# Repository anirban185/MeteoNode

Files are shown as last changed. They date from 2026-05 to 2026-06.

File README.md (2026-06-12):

# MeteoNode
 
MeteoNode is a small solar-powered ESP32 weather node. The idea is to pull regional forecast data from Open-Meteo and adjust it using pressure, humidity, and temperature trends measured locally by the node itself. Instead of sending data somewhere else to process, the ESP32 handles everything on-device using a lightweight Bayesian-style system.

# Why
 
Regional forecasts are accurate at scale but they update slowly. Local pressure drops and humidity spikes can show incoming weather changes earlier than a regional model would catch. I wanted to see if those local trends could make a forecast feel more responsive at a specific location on a small standalone device.
 
Something like:
 
```
Open-Meteo rain chance: 40%
Pressure dropping fast
Humidity rising
 
=> local adjusted: 65%
```
 
It's not meant to replace anything. More of an experiment.

# How I built it
 
Most of the early time went into research and parts selection, not actual building.
 
My original sensor choice was the BME280 because it handles temperature, humidity, and pressure in one chip. While reading through datasheets and long-term testing threads I found that combined environmental sensors can slightly skew their own readings because of internal heat generation. So I split it into a BMP280 for pressure and an HTU21D for temperature and humidity. Separating them also made physical placement easier since they no longer needed to sit right next to each other.
 
The power system took the longest.
 
I initially looked at the TP4056 for charging but solar panels don't output stable voltage, they fluctuate constantly depending on sunlight and load. The TP4056 needs a stable input to work properly. I switched to the TP5000 because its buck converter handles variable input between 4.5V and 9V without needing anything extra to stabilize it.
 
For the battery I moved away from standard 18650 Li-ion. The node is meant to sit outside unattended in direct sun, and Li-ion can go into thermal runaway at high temperatures. LiFePO4 needs over 270°C to reach thermal runaway and doesn't sustain a fire even if it does ignite, so it was the obvious choice. I went with a Huaxing 32700 6000mAh solar grade cell.
 
Powering the ESP32 directly from the LiFePO4 cell also came with a problem I found during research. During WiFi transmission the ESP32 pulls sudden high current spikes that can drop the supply voltage and cause brownouts and random reboots, especially with solar-grade cells or long wiring. To fix that I added a 1000uF electrolytic capacitor for the transient demand and a 100nF ceramic for high-frequency RF decoupling.
 
The soft-latch circuit was probably the most interesting part. The node runs on a deep sleep cycle normally, but I also wanted a way for it to fully disconnect itself if the battery stays critically low for too long, to avoid deep discharge damage. The circuit uses an FDN304P P-channel MOSFET as the main switch and a 2N7000 N-channel to control it. The ESP32 holds the latch on after waking. If battery voltage drops below the cutoff the firmware pulls the latch low, the MOSFET opens, and power is cut completely. Manual restart needed after that.
 
One more thing the direct battery connection created was an ADC reference problem. Since the ESP32 runs off the cell directly there is no stable 3.3V reference, so the ADC reading drifts with battery voltage. The firmware handles this by reading the ESP32's internal 1.1V bandgap reference each wake cycle and using it to calculate the actual VREF before reading the battery.

# Enclosure
 
I wanted the enclosure done properly, not just a box you shove everything into.
 
The first decision was keeping the battery separate from the main electronics. The battery generates heat when charging, and heat near the sensors would throw off the readings, so the battery got its own compartment. I modeled it around the actual cell dimensions (32.2 x 70.5mm), added two side holes for the wires to pass through (a center hole would've conflicted with the pole clamp), and added tabs on both the box and lid for M3 bolts. There are grooves on the mating faces for O-rings to seal it.
 
The main electronics box went through a couple of iterations. I first made a single box, then split the interior into two sections: a sealed ESP32/power side and a vented sensor side. I live in a part of Assam where humidity sits between 80 and 90 percent most of the year and hits 100 during monsoon. The ESP side is fully sealed with an O-ring groove on the lid. The sensor side has ventilation holes so the HTU21D is actually reading ambient air, not trapped air. I added rails inside both sides to mount the sensors and perfboard without floating them around loose.
 
For mounting I took inspiration from motor shaft couplers. I made a pipe-shaped clamp that slides over the main pole with set screws, and bolted the electronics box to that. The whole thing sits on a 2-meter pole with a rectangular channel running through it for the battery wires.
 
Since I couldn't find the O-rings I needed, I ended up making gaskets instead and finished the assembly.
 
CAD files are in `Hardware/Cad files/` as STEP files. There's a full assembly plus individual parts: battery box, main electronics box, pole mount bracket, and pole.

OnShape Link: https://cad.onshape.com/documents/560823f845b4e1dbdcd98f5f/w/6feb564b6c844b09aff696f7/e/17a8fd3166888350d1755295

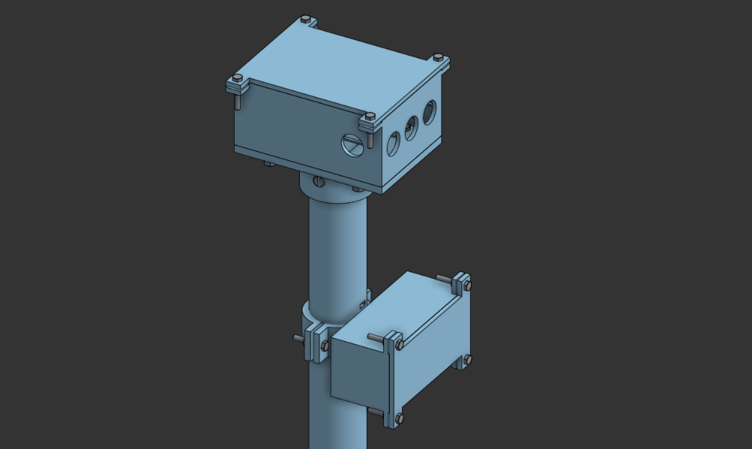
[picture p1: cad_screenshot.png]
cad Screenshot

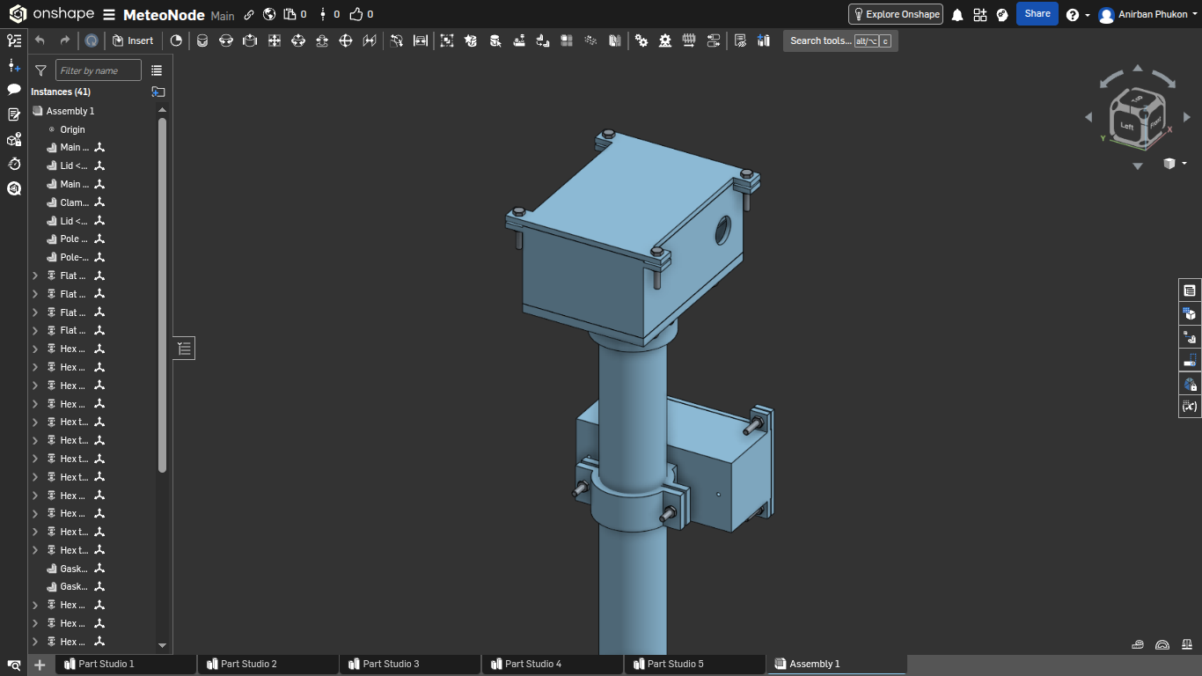
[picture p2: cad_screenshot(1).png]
cad_screenshot(1)

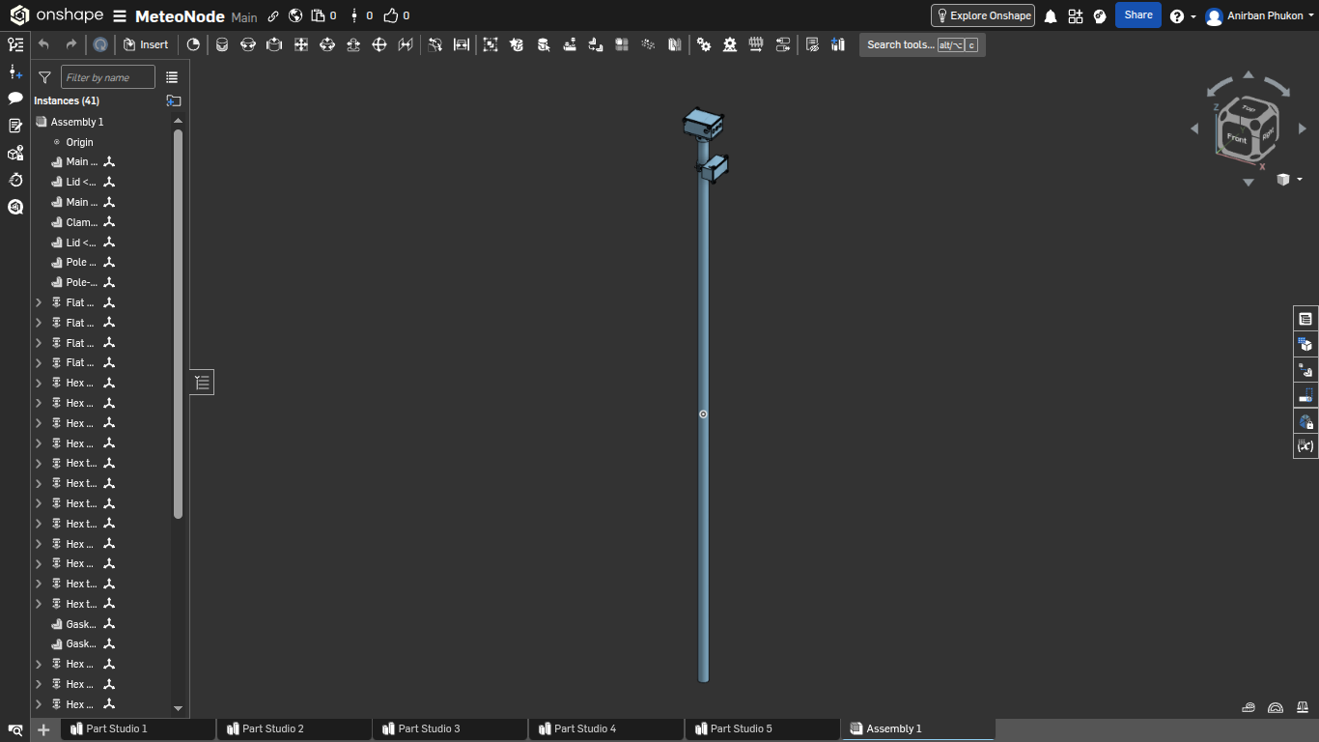
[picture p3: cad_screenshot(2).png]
cad screenshot(2)


# Hardware
 
| Component | Purpose |
|---|---|
| ESP32-WROOM-32UE Dev Board | Main controller |
| BMP280 | Pressure sensor |
| HTU21D | Temperature and humidity sensor |
| TP5000 Charge Module | LiFePO4 solar charging |
| Huaxing 32700 6000mAh LiFePO4 | Power storage |
| 2W 5V Solar Panel ×2 | Solar input |
| FDN304P P-Channel MOSFET | High-side power switch |
| 2N7000 N-Channel MOSFET | Soft-latch control |
| 1000uF Electrolytic Capacitor | WiFi current spike stabilization |
| 100nF Ceramic Capacitor | RF decoupling |
| 1N5819 Schottky Diode | Reverse current protection |
| 3A Glass Fuse + Holder | Overcurrent protection |
| MT76813DBI WiFi Antenna | External antenna |
| 100K Resistor | Voltage divider + PMOS gate pull-up |
| 10K Resistor | NMOS gate pull-down |
| 1K Resistor | ESP32 overcurrent protection |
 
Everything is from ElectronicsComp.

# Block diagram
 
block diagram

# Wiring diagram

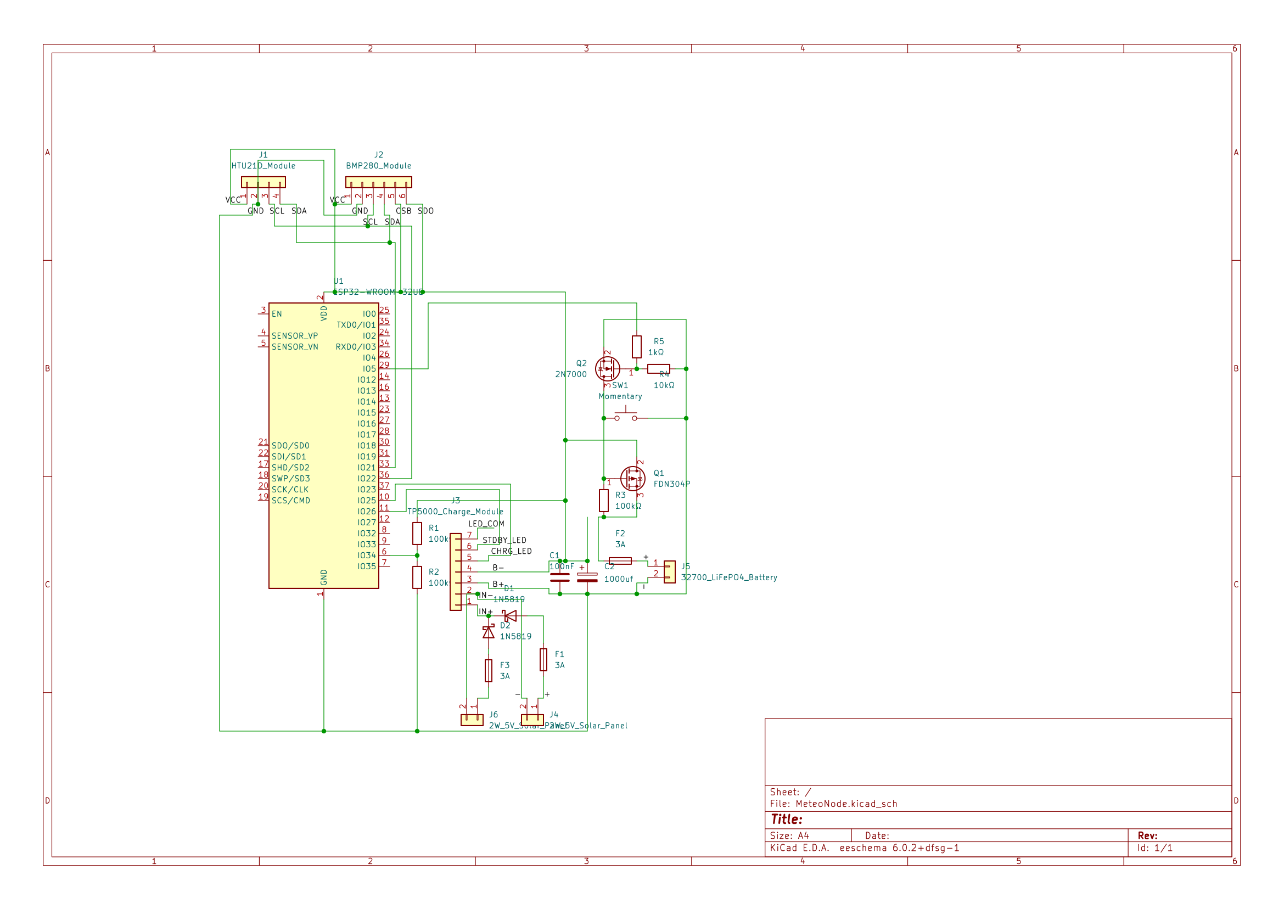
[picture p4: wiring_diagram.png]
block diagram


Open the image in a new tab and zoom to view it in full resolution.

# Firmware
 
Each wake cycle the ESP32 reads the sensors, fetches a forecast from Open-Meteo, adjusts the rain probability using local trends from RTC memory, and goes back to sleep. RTC memory keeps the last 4 readings alive across deep sleep so the trend analysis always has something to work with.
 
Full setup and wiring details are in `Firmware/README.md`.

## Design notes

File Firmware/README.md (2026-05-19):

## MeteoNode Firmware
 
This is the firmware for the MeteoNode. The core idea is to wake up, read the sensors, pull a regional forecast from Open-Meteo, adjust the rain probability using local pressure and humidity trends, and go back to sleep. Everything runs on the ESP32 locally, no external processing.

## Libraries
 
Install these through PlatformIO or the Arduino Library Manager. If you're using the platformio.ini it will handle this automatically.
 
- Adafruit BMP280
- Adafruit Unified Sensor
- HTU21D (enjoyneering's version)
- ArduinoJson v7
 
## Setup
 
At the top of `Firmware.ino` there are defines for WiFi credentials and the node's coordinates. These need to be set before flashing.
 
```cpp
#define WIFI_SSID        "YOUR_SSID"
#define WIFI_PASSWORD    "YOUR_PASSWORD"
 
#define LATITUDE         "Node's Latitude"
#define LONGITUDE        "Node's Longitude"
```
 
The coordinates are passed directly to the Open-Meteo API, so they should be as accurate as possible for the forecast to be useful. `SLEEP_SECONDS` is 15 minutes by default. `LATCH_HOLD_PIN` is GPIO5, change it if the 2N7000 gate is wired differently.

## Wiring
 
**I2C**  Both sensors share the same bus.
- SDA  GPIO 21
- SCL  GPIO 22
- BMP280 default address is 0x76, code tries 0x77 as a fallback
- HTU21D is always 0x40
**Battery ADC**  100K-100K voltage divider into GPIO34.
```
BAT+  100K  GPIO34  100K  GND
```
 
**Soft latch**  GPIO5 held HIGH keeps the system on. When battery voltage drops below the critical threshold the firmware pulls it LOW, the MOSFET latch opens, and power is cut completely. After that it requires a manual restart.

## Battery Voltage and the ADC Problem
 
Since the ESP32 is powered directly from the LiFePO4 cell there is no stable 3.3V reference for the ADC. The supply voltage shifts between roughly 3.0V and 3.6V depending on charge state, which would make a fixed-reference ADC reading meaningless.
 
To fix this the firmware reads the ESP32's internal 1.1V bandgap reference on every wake cycle and uses that to figure out what VREF actually is at that moment. The battery voltage is then calculated using the calibrated VREF rather than assuming a fixed value. It's not laboratory accurate but it's consistent and close enough to catch low voltage events reliably.
 
Thresholds:
- Below 2.90V  cuts power via latch
- Below 3.00V  skips WiFi, reads sensors and sleeps
- Normal otherwise
 
## Wake Cycle
 
Every time the ESP32 wakes from deep sleep it runs through this sequence:
 
1. Hold latch pin HIGH immediately so the system stays on
2. Read battery voltage, cut power or skip WiFi if needed
3. Read BMP280 and HTU21D over I2C
4. Push readings into the RTC ring buffer
5. Connect to WiFi and fetch Open-Meteo forecast if battery allows
6. Calculate adjusted local rain probability
7. Print report to serial
8. Sleep for `SLEEP_SECONDS`
The RTC ring buffer stores the last 4 pressure, humidity, and temperature readings across sleep cycles. It needs at least 2 samples before trend analysis activates. At 15 minute intervals that means one hour of history to work with.

## Forecast Adjustment
 
Open-Meteo provides a regional rain probability. The local sensors can sometimes pick up changes faster, pressure drops in particular tend to precede incoming weather before the regional model updates. The firmware calculates a slope across the RTC history for pressure, humidity, and temperature and uses that to shift the Open-Meteo probability up or down.
 
The adjustment runs in logit space rather than raw percentage so the result stays naturally bounded between 0 and 100 without any clamping.
 
The next 3 hourly values from Open-Meteo are averaged to smooth out short-term noise before the adjustment is applied.

## Serial Output
 
Baud rate is 115200. A typical cycle looks like this:
 
```
boot 4
bat: 3.31V
P=1008.42 hPa T=27.3 C H=81.2% Bat=3.31V
wifi connecting.... ok
forecast: rain=42.0% temp=28.1C hum=79.0%
--- meteonode ---
boot #4
battery: 3.31V
pressure: 1008.42 hPa
temp: 27.3C
humidity: 81.2%
open-meteo rain: 42.0%
local adjusted: 61.3%
condition: Likely Rain
----------------
sleeping 900s
```
 
Disconnect serial before deploying outside. Keeping UART active draws extra current through the whole sleep cycle.

## Security Note
 
The firmware uses `client.setInsecure()` to connect to Open-Meteo over HTTPS. The connection is encrypted but the server identity is not verified because pinning a certificate on an ESP32 is more complexity than this project needs. Fine for a local weather node on a home network, but worth knowing if you're deploying it somewhere else.

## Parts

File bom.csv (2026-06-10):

Name | Purpose | Quantity | Total Cost (USD) | Link | Distributor
10K ohm Resistor | Gate pull-down resistor for the NMOS | 5 | 0.03 | https://www.electronicscomp.com/10k-ohm-resistance?search=10k%20Ohm%20resistor | ElectronicsComp
100K ohm Resistor | Battery monitor and PMOS gate pull-up resistor. | 5 | 0.03 | https://www.electronicscomp.com/100k-ohm-resistance?search=100k%20Ohm%20resistor | ElectronicsComp
1K ohm Resistor | Protection for the ESP32 from Overcurrent | 5 | 0.03 | https://www.electronicscomp.com/1k-ohm-resistance?search=1k%20Ohm%20resistor | ElectronicsComp
2N7000 N-Channel MOSFET | Electronic lock for the Soft-Latch | 2 | 0.20 | https://www.electronicscomp.com/2n7000-n-channel-enhancement-mode-fet-to-92-package?search=2N7000 | ElectronicsComp
FDN304P P-Channel MOSFET | Main power switch for soft-latch | 2 | 0.30 | https://www.electronicscomp.com/fdn304p-mosfet-smd-sot-23-package-20v-2.4a-p-channel-mosfet?search=FDN304P | ElectronicsComp
Fuse Holder | Housing for the glass fuse | 1 | 0.10 | https://www.electronicscomp.com/fuse-holder-pcb-mount-20mm?search=fuse%20holder | ElectronicsComp
3 Amp 250V Glass Fuse | Short-circuit protection | 6 | 0.25 | https://www.electronicscomp.com/3-amp-250v-glass-fuse-20mm?search=fuse&sort=p.price&order=ASC | ElectronicsComp
Prototyping Board | mounting and routing platform for core electronics | 2 | 1.00 | https://www.electronicscomp.com/6x8-cm-double-sided-universal-pcb-india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 | ElectronicsComp
28AWG Silicone Wire 10 m (Blue) | Logic Routing (I2C for AHT20/BMP280, ADC telemetry) | 1 | 0.60 | https://www.electronicscomp.com/tools-connectors/wires-cables/silicone-wires/24-to-30-awg/high-quality-ultra-flexible-28awg-silicone-wire-10-m-blue | ElectronicsComp
20AWG Silicone Wire 1m (Black) + 1m (Red) | Power Distribution (Solar, TP5000, Battery, ESP32 VIN/GND) | 1 | 1.10 | https://www.electronicscomp.com/tools-connectors/wires-cables/silicone-wires/18-to-22-awg/high-quality-ultra-flexible-20awg-silicone-wire-1m-black-1m-red | ElectronicsComp
MT76813DBI WiFi Antenna | Antenna for the ESP | 1 | 0.60 | https://www.electronicscomp.com/mt76813dbi-esp8266-serial-wifi-wireless-gain-antenna?search=wifi%20antenna | ElectronicsComp
100nf(0.1uf) Ceramic Capacitor | To decouple High-frequency RF noise | 5 | 0.05 | https://www.electronicscomp.com/0.1uf-104-ceramic-capacitor?search=capacitor%200.1uf | ElectronicsComp
1000uF 10V Electrolytic Capacitor | To stabilize voltage in wifi current spike | 2 | 0.25 | https://www.electronicscomp.com/1000uf-10v-electrolytic-capacitor?search=capacitor%201000uf | ElectronicsComp
ESP32-DevKitC ESP32-WROOM-32UE Development board | The main MCU | 1 | 7.25 | https://www.amazon.in/ESP32-DevKitC-32UE-ESP32-Devkit-Board-4MB/dp/B0CKPPQYCB/ | Amazon.in
Huaxing 32700 6000mAh Solar Grade LiFePO4 Battery | High-capacity 3.2V power storage | 1 | 2.50 | https://www.electronicscomp.com/hx-ifr32700-32v-6000mah-1c-lifepo4-battery-solar-grade?search=LiFePO4&page=2 | ElectronicsComp
TP5000 Charge Module | LiFePO4 Buck Charger | 1 | 1.00 | https://www.electronicscomp.com/tp5000-3.6v-4.2v-1a-lithiumbattery-charger-module?search=TP5000%20 | ElectronicsComp
1N5819 Schottky Diode | Reverse-Current Protection | 5 | 0.30 | https://www.electronicscomp.com/1n5419-schottky-barrier-diode?search=1N5819 | ElectronicsComp
2W 5V Solar Panel | 5V Power Generation | 2 | 4.00 | https://www.electronicscomp.com/robotics-parts-accesories/solar-panel-cell/solar-panel-5v-2w | ElectronicsComp
BMP280 Module | I2C Barometric Pressure Sensor | 1 | 0.90 | https://www.electronicscomp.com/bmp280-barometric-pressure-altitude-sensor-module-india?search=BMP280 | ElectronicsComp
HTU21D Module | Temperature & Humidity Sensor | 1 | 1.60 | https://www.electronicscomp.com/htu21d-temperature-and-humidity-sensor-module?search=HTu21 | ElectronicsComp

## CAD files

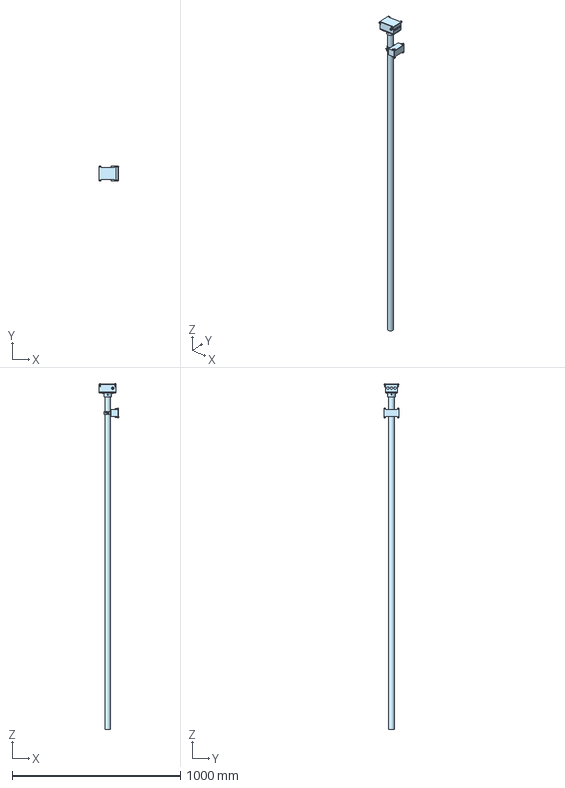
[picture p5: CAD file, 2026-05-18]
Hardware/Cad files/Assembly.step
116.0 x 90.0 x 2055.1 mm
Main battery compartment
Flat point slotted set screw M8x1.25 x 8 x 4
Lid x 2
Gasket x 2
Hex thin nut grade A & B M3 x 14
Hex head bolt grade B M3x0.50 x 20 x 10
Clamp
Pole
Pole-Mount Bracket
Main Box
Hex flange bolt small M5x0.80 x 10 x 4

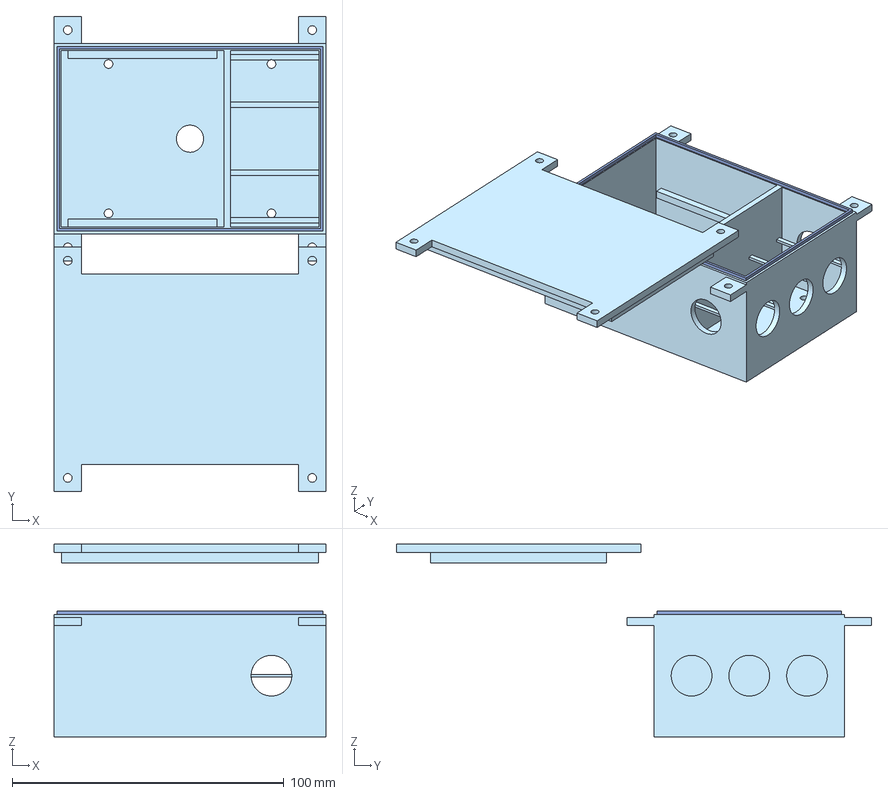
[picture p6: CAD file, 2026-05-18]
Hardware/Cad files/Main Electronics Box.step
100.0 x 174.9 x 70.9 mm

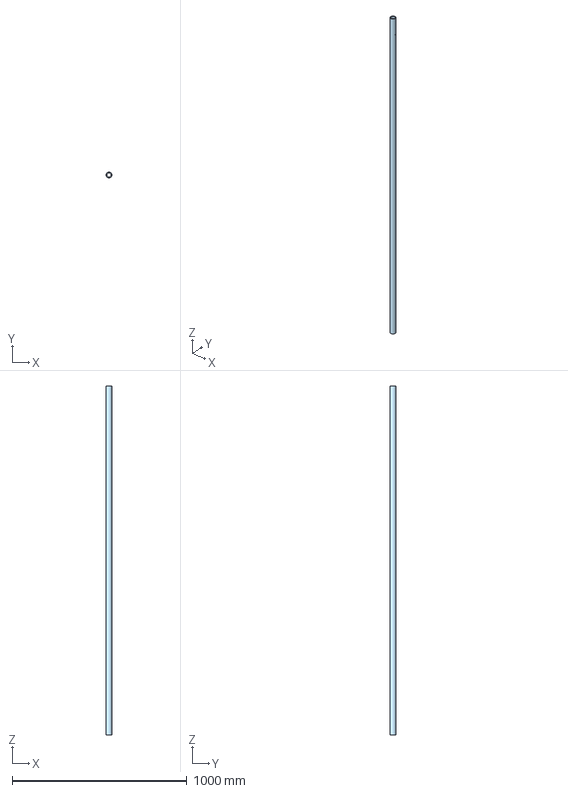
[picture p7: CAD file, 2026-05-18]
Hardware/Cad files/Pole.step
34.0 x 34.0 x 2000.0 mm

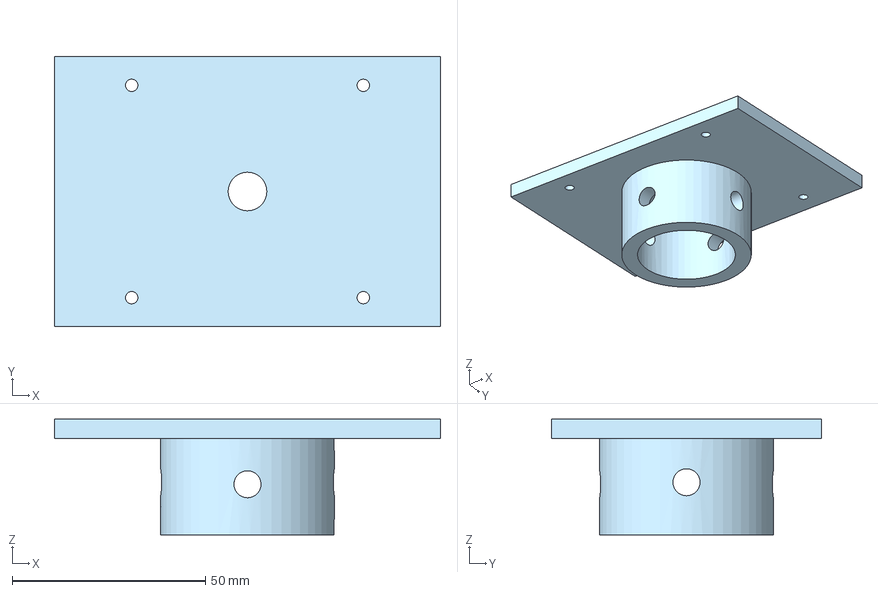
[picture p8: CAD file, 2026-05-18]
Hardware/Cad files/Pole-Mount Bracket.step
100.0 x 70.0 x 30.0 mm

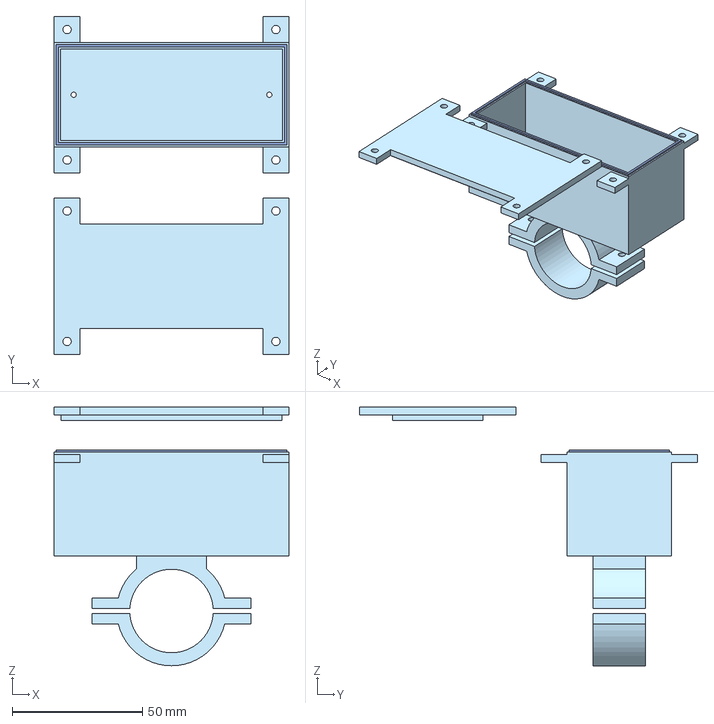
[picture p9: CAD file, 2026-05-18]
Hardware/Cad files/Battery Box.step
90.0 x 129.5 x 99.1 mm

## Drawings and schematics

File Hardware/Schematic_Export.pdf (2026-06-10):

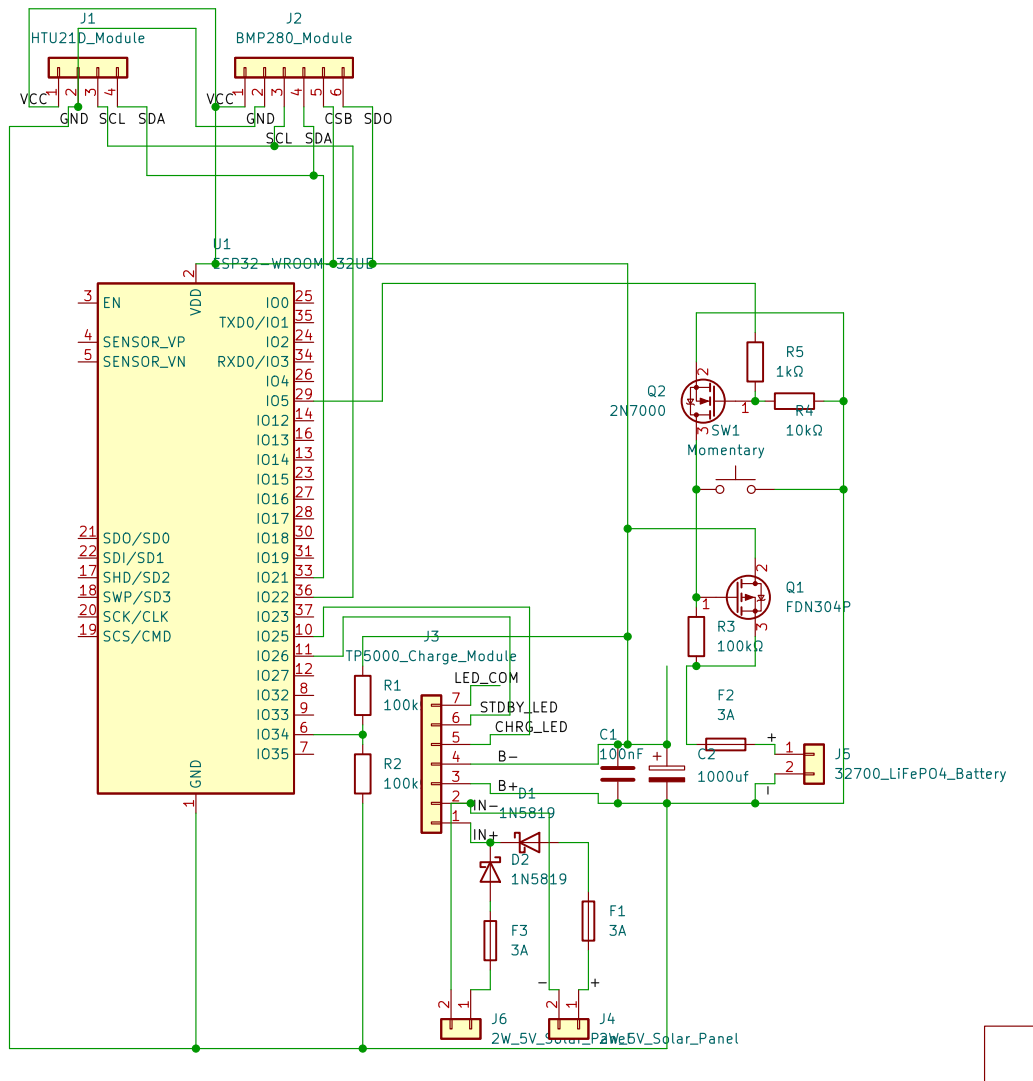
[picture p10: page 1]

2 SCK/CLK 20 SDO/SD0 21 SDI/SD1 22

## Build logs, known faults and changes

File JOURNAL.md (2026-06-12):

<!--
  This journal is auto generated by Stasis.
-->

# 6/12/2026 3 PM - Adjustments

_Time spent: 0.08333333333333333h_

According to the reviewer notes, my first and only task is adding CAD photos to the README, so I added some screenshots to the repo root and added them to the README.md. After this, I am gonna update the journal to include this entry on GitHub and resubmit.







# 6/10/2026 6 PM - Adjustments

_Time spent: 0.75h_

Based on the design feedback, my first task is renaming the BOM to bom.csv, which I did, but I didn’t have the energy to continue and went to bed without writing the journal. 

The next task is adding a diagram image to the read me, which was easy enough because my schematic was built to be a wiring diagram too, so I plotted it into a PDF, converted it into PNG and added it to the readme. While doing that,

 I had 2 resistors left without specifying values, so I edited there vaule and used the updated PNG, and also updated the schematic on the GitHub repo

Then came the task of adding a simple enough, but still needed two tries because I used the wrong link the first time.
       
Before submitting the design i wanted to test if all items that i listed in the bom so i logged into my Electronicscomp account and viewed the cart, and the esp devboard was out off stock and I couldn’t find an ESP32 with a IPEX on Electronicscomp so i had to go to Amazon.in and chose a ESP32 from there luckily i found the exact model i was using before. So I added it to the BOM and ended the session.





# 5/19/2026 9 AM - Self Review

_Time spent: 0.75h_

So everything was complete and ready to be submitted, but I wanted to review it. Since using AI as a support tool is allowed, I fed the GitHub repo to Claude to check for errors, and it found some flaws.

First, there were some typos in the BOM, so I fixed them. Then it suggested replacing "DynamicJsonDocument doc(8192);" with "JsonDocument doc" cause ArduinoJson v7 handles sizing automatically. It also suggested I halt the system instead of sleeping when the soft latch fails. One more suggestion was to add a "
platformio.ini" file with the libraries and settings needed to upload to the ESP32. The last suggestion was to add a note about TLS in the Firmware README.md.

I also updated the root README.md to include info about the enclosure. And that was it. This was a very short session, maybe the shortest one yet.




# 5/18/2026 4 PM - CAD Development

_Time spent: 4h_

So today's task was finishing the CAD files. First was the battery compartment. I wanted a separate battery compartment 'cause I didn’t want the battery heat to cause inaccurate readings, so I looked up my battery's dimensions (32.2 x 70.5mm). I made a sketch, drew a 40 by 90 rectangle, extruded it by 40 mm, and used the shell tool to hollow it out. Then I added 2 holes in the side for the battery wires to go to the pole.

At first, I was making a single hole in the middle, but then I remembered the clamp will be in the center. I could have made a hole straight through the clamp so that the wires wouldn't be visible from the outside, but that would just add unnecessary complexity. So, I made 2 holes in the sides instead and moved on to make the clamp. Making the clamp took some time 'cause I had never built anything like it before, but it was mostly easy. Splitting it took some time 'cause I tried to split it with a sketched line but it didn’t work, and I had to make a new plane to split the clamp.

After that, I made a lid and extruded tabs on the side to bolt it without taking up space on the inside. Then I added tabs on the box too and added M3 holes on the tabs of both parts. I added some grooves on the touching walls of the lid and the box to fit some O-rings for a better seal.

After the battery box, I needed something to connect the main electronics box to the pole. I sketched a rectangle the size of the base of the main box and extruded it. To attach this part, I took inspiration from things that attach to motor shafts. I extruded a circle into a pipe shape that will fit around the main pole and added some holes to it to drive set screws in. I added 4 holes to it so I could bolt the main electronics box to it, and added holes to the box too. However, the bolts holding the lid would get in the way, so I removed the bolt holes from the main box's lid and added tabs similar to the battery box.

Then I made the pole, 2 meters tall with a small rectangular hole in it for the battery wires.

I assembled everything, but I couldn't find the O-rings I needed, so I had to make gaskets instead. Then I finished the assembly and ended the session.










Uploading Screenshot_2026-05-18_19-25-16.png...







# 5/16/2026 5 PM - CAD Development

_Time spent: 2h_

So I was gonna finish up the project after making the GitHub repo and the firmware, but it felt incomplete without a 3D model of the enclosure. So today's task was CAD.
First, I tried designing the main concept in my head. The first design that came to mind was a pipe buried in the ground with a main enclosure on top, and solar panels sitting on the box. I made a 90x50 rectangle with the center point tool and extruded it 90mm. Then I hollowed it out using the shell tool. After that, I created a new part studio, made a lid, and cut out countersunk holes for the screws.
I was trying to figure out where and how I'll place the Components in the box, and I thought I should place the battery differently cause it can heat up and throw off the sensor readings. So I changed the box's dimensions to 100 x 70 x 45mm. Then I added holes for ventilation. I needed something for the lid screws to go into, so I used the offset tool to make a construction rectangle 10mm from the edge. I made 6mm circles on the corners, extruded them 8mm, and made holes for the screws.
Even though I was gonna place the battery differently, I still wanted to isolate the sensors from the TP5000 and the soft latch. So I divided the main box into two parts: a sensor part (40x70x45) and an ESP32/power part (60x70x45). The dimensions aren't fully accurate cause the inner and outer walls take up space.
So now I had an ESP32 side, and I want to protect it from moisture cause I live in a part of Assam where average humidity is 80 to 90 percent, and it can hit 100 in the monsoon. My plan is to totally seal the ESP side. So I removed the ventilation holes from the ESP side and added more to the sensor side. To completely seal it, I needed a good seal on the lid, so I carved a 1mm wide, 1.2mm deep line on the lip of the walls for O-rings, and did the same to the lid.
I drilled some holes in the divider wall to pass wires between the ESP and sensor sides. I also drilled a hole in the bottom centre of the box so I can connect the battery by running a wire down the pipe, and I'm thinking of running the solar panel wires the same way.
To mount the sensors right in the airflow from the ventilation holes without blocking it, I decided to make rails. So that's what I did, I built some rails for the sensors and for the perfboard housing the ESP32 and power circuits.
And that was it. I didn’t do much today, just a 2-hour session, but I'm thinking of finishing the CAD and submitting the project tomorrow.














# 5/12/2026 4 PM - Parts Selection

_Time spent: 1.75h_

So today's first task was adding the parts I used yesterday to the BOM. My first part to look for was the 2N7000, but when I opened the ElectronicsComp site, I was logged out. I tried to log back in, but after entering my credentials, I got a blank page. Then I tried Firefox, cause my current browser is Brave, which has shields that sometimes mess with websites. I tried to log in using Firefox but still got a blank page. I tried making a new account, still a blank space. I tried other ways like signing in with a Google account, and finally, making a new account with a different Google account worked. I was back in.

I used my BOM list to add parts to my cart and then proceeded to add the 2N7000 and the resistors. However, I couldn't find the specific P-channel MOSFET I was looking for, nor could I find similar MOSFETs in a through-hole form. So, I will have to use an FDN304P P-Channel MOSFET in a SOT-23 package using the dead-bug soldering technique.

After adding everything, I opened my cart, and what did I see? Three items were out of stock: the AHT20, the 6V 3W solar panel, and the main MCU. I researched alternatives for these parts. For the MCU, I found an AI Thinker NodeMCU-32S ESP32 Development board with IPEX. For the humidity and temperature sensor, I researched the best options on ElectronicsComp and found the SHT41, SHT31, SHT40, and HTU21D. After some research, I picked the SHT41 cause it was the newest gen chip with the best overall performance. For solar, I chose two 5V 2W solar panels.

After adding everything to the cart, what did I see? The newly added ESP and the SHT41 were out of stock. Turns out, unlike other sites, ElectronicsComp has microscopic text indicating availability in the product description and has no other labels to indicate a product is out of stock. So, first I tried to switch the SHT41 with the SHT40, and it was out of stock too. Then I tried the SHT35; it was out of stock too. Then the SHT31—not in stock either. The last hope for the SHT family was the SHT30, and can you guess what happened? Yep, out of stock. So the last option was the HTU21D. Luckily, it was in stock.

Then came the ESP. I looked at other options with an IPEX port, but most were bare chips. I've had a lot of trouble with bare chips before cause I face uploading errors with them every time. Finally, I found an ESP32-WROOM-32UE development board, which is mostly similar to the original choice.

I had other tasks for today, but this session was way too frustrating. I had to end the session.










# 5/11/2026 6 PM - Schematic Design

_Time spent: 3.25h_

The objective for today’s session was to translate the BOM into a functional schematic. I initially spent time looking for dedicated footprints or integrated library models for the specific modules I'm using (TP5000, AHT20/BMP280 break-outs), but found none that were reliable. I decided to follow the standard modular design approach: using header connectors and precise pin labeling to represent the modules. I placed the ESP32-WROOM-32U as the core, followed by 2-pin connectors for the LiFePO4 battery and solar input, and 4-pin I2C rails for the sensors.

The layout phase was iterative and tedious. Labeling the 4-pin I2C sensors was straightforward, but the high-pin-count connectors for the ESP32 and power management required multiple orientation changes to minimize cross-over. Routing became the bottleneck; as more wires were involved, the "ratsnest" grew messy. I had to re-route several traces to maintain a clean logic flow and ensure the safety systems were properly isolated.

A key addition today was integrating the TP5000’s status pins. The module has pins for external LEDs (Charging/Standby). I wired these to the ESP32's GPIOs so I can monitor the charge state remotely via software. However, the biggest challenge was the remote power-down requirement. I designed a soft-latching power circuit using a high-side P-channel MOSFET as the main switch, controlled by a small N-channel MOSFET. This allows the ESP32 to "hold" its own power on after a button press and programmatically "suicide" (cut its own power) when a shutdown command is received. I also added a 100k-100k voltage divider on the battery rail, tied to an ADC pin, to monitor the LiFePO4’s discharge curve.





# 5/10/2026 10 AM - Parts Selection

_Time spent: 2.75h_

So today's task is to complete the BOM. Before starting the session, I was reading the guidelines and FAQ on the Stasis website, and I read that the hardware grant is given as a card by Hack Club Bank (HCB). Most Indian suppliers don't support this card, including the suppliers I am using, like Robu and Makerbazar. So I read more, and they listed some Indian suppliers that do accept it. I first picked an item, the TP5000 charger module, and tried to find it on every supplier given in the guidelines. Only one supplier had it: ElectronicsComp. I tried that with the BMP280 and got the same results, only ElectronicsComp. So I had to choose it as my supplier.
  Then I tried to find the parts I needed. I found most of them, but I didn’t find the same solar battery. So I looked at alternatives. I found a different model battery by the same brand as before with similar performance, but at a higher price. For solar, I found a 6V 3-watt solar panel. For the AHT20, I found it, but it was from a different brand. The main sensor was, of course, the same AHT20, but the circuit looked different. I had to compare datasheets and they are identical in performance.
After finding the parts I had selected before in a different supplier, it was time to select the other parts. For the MCU, I went with the ESP32-WROOM-32U development board. This board doesn’t have a PCB antenna, so I needed an external one. There was an omnidirectional antenna on ElectronicsComp, but I was looking for something directional cause I don’t know where I will place the sensor node. Even though my WiFi has a great range, I still preferred a directional one and tried to find one outside of ElectronicsComp. I was looking for those PCB Yagi antennas, but all I could find were some big aluminium Yagi antennas, so I had to select the omnidirectional one on ElectronicsComp.
The next question was how am I gonna power the ESP32, cause I have seen people feeding direct LiFePO4 cells to the ESP 3v3 pin. The ESP supports 3v to 3.6v, and the battery outputs a max of 3.65v. That 0.05V is not a problem cause the voltage drops immediately when pulling current, but what about charging it? Cause the module uses max battery voltage when charging, which is 3.65V. I did some research; some people used the battery directly, some said it is risky, but the answer was in the TP5000’s data sheet. Turns out the TP5000 doesn’t use the battery max voltage; it uses 3.6v, which is fine and within the limit of the ESP voltage rating.
When researching powering an ESP directly with the battery, I found a problem. When transmitting WiFi signals, there is a sudden current peak, and that could drop the voltage and result in the ESP rebooting, especially when using solar-grade batteries. To counter that, I added a 1000uF Electrolytic Capacitor and a 100nF ceramic capacitor to decouple high-frequency RF noise.
At that point, the ElectronicsComp site got very slow. I don’t know if it was my hardware or their server, but it was very slow. But I didn’t stop and tried to find some wires. I selected 20AWG Silicone Wire 1m (Black) + 1m (Red) for power and 28AWG Silicone Wire 10m (Blue) for logic level things. Then a perfboard, and ended the session by adding some 3 amp fuses and 1 fuse holder.








# 5/8/2026 3 AM - Parts Selection

_Time spent: 2h_

i am writing this today cause the 2 hour session yesterday ran too late and i went to sleep before documenting it. yesterday's task was selecting parts for the project. the session took a full 2 hours cause i had to read datasheets to make sure the components actually work together. first i needed a sensor for temperature, humidity, and pressure. my first pick was the bme280, but research showed a flaw: the chip's internal heating messes with its own environmental readings. to fix this, i picked an aht20 and a bmp280. this way i can place the sensors at a distance from each other so their heat doesn't interfere.
next i needed solar panels that output about 2 watts. robu didn't have the mini panels, so i had to search makerbazar to find 6v panels. this is where the charging module became critical. my go-to is the tp4056, but solar panels don't output a stable voltage; they fluctuate wildly based on sunlight and load. the tp4056 requires a strict 5v input to work reliably. i looked for alternatives and picked the tp5000. it is a charging module that has a buck converter circuit with an input range of 4.5v to 9v. this switching architecture handles the unpredictable solar voltage fluctuations perfectly without needing an extra stabilization circuit. i also added 1n5819 schottky diodes to stop the battery from discharging back into the panels at night.
the last part of yesterday's session was power storage. i was going to use classic 18650 li-ion cells, but this node will be outdoors in the sun unsupervised. standard li-ion is risky in high heat and can go into explosive thermal runaway. i looked into safer chemistries and chose lifepo4. it requires temperatures over 270°c for thermal runaway, and because it doesn't release internal oxygen, it won't sustain a fire even if ignited. i selected huaxing’s 32700 solar grade lifepo4 cell from makerbazar and ended the session.








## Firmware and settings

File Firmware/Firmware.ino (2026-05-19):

#include <Arduino.h>
#include <Wire.h>
#include <WiFi.h>
#include <WiFiClientSecure.h>
#include <HTTPClient.h>
#include <ArduinoJson.h>
#include <Adafruit_BMP280.h>
#include <HTU21D.h>
#include <esp_adc_cal.h>

// WiFi credentials

#define WIFI_SSID        "YOUR_SSID"
#define WIFI_PASSWORD    "YOUR_PASSWORD"

// Node coordinates

#define LATITUDE         "Node's Latitude"
#define LONGITUDE        "Node's Longitude"

// Deep sleep intervals

#define SLEEP_SECONDS    (15 * 60)

#define BAT_ADC_PIN      34
#define BAT_DIVIDER_RATIO 2.0f
#define ADC_MAX          4095.0f

// battery voltage thresholds

#define BAT_CRITICAL_V   2.90f
#define BAT_LOW_V        3.00f

// Soft-latch hold pin

#define LATCH_HOLD_PIN   5

// Trend history storing in RTC

#define HISTORY_LEN      4

// RTC Memory

RTC_DATA_ATTR float  rtc_pressure[HISTORY_LEN]    = {0};
RTC_DATA_ATTR float  rtc_humidity[HISTORY_LEN]    = {0};
RTC_DATA_ATTR float  rtc_temperature[HISTORY_LEN] = {0};
RTC_DATA_ATTR uint8_t rtc_head                    = 0;
RTC_DATA_ATTR uint8_t rtc_count                   = 0;
RTC_DATA_ATTR uint32_t rtc_boot_count             = 0;

// Globals

Adafruit_BMP280 bmp;
HTU21D          htu;

struct SensorData {
  float pressure_hpa;
  float temperature_c;
  float humidity_pct;
  float battery_v;
  bool  sensor_ok;
};

struct ForecastData {
  float rain_chance;
  float forecast_temp_c;
  float forecast_humidity;
  bool  fetch_ok;
};

struct LocalForecast {
  float adjusted_rain_chance;
  String condition_label;
};

// battery 

float readBatteryVoltage() {
  esp_adc_cal_characteristics_t adc_chars;
  esp_adc_cal_characterize(ADC_UNIT_1, ADC_ATTEN_DB_11, ADC_WIDTH_BIT_12, 1100, &adc_chars);

  uint32_t sum = 0;
  for (int i = 0; i < 16; i++) {
    sum += adc1_get_raw(ADC1_CHANNEL_6);  // GPIO 34
    delay(2);
  }
  uint32_t raw_avg = sum / 16;

  uint32_t mv = esp_adc_cal_raw_to_voltage(raw_avg, &adc_chars);
  return (mv / 1000.0f) * BAT_DIVIDER_RATIO;
}

void cutPower() {
  Serial.println("battery critical, cutting power");
  Serial.flush();
  delay(100);
  digitalWrite(LATCH_HOLD_PIN, LOW);
  while (true) { delay(1000); }
}

SensorData readSensors() {
  SensorData d = {};
  
  // Sensors

  bool bmp_ok = bmp.begin(0x76);
  if (!bmp_ok) bmp_ok = bmp.begin(0x77);
  bool htu_ok = htu.begin();

  if (!bmp_ok || !htu_ok) {
    Serial.printf("sensor init fail: BMP=%d HTU=%d\n", bmp_ok, htu_ok);
    d.sensor_ok = false;
    return d;
  }

  bmp.setSampling(
    Adafruit_BMP280::MODE_FORCED,
    Adafruit_BMP280::SAMPLING_X2,
    Adafruit_BMP280::SAMPLING_X16,
    Adafruit_BMP280::FILTER_X4,
    Adafruit_BMP280::STANDBY_MS_1
  );

  delay(100);

  d.pressure_hpa   = bmp.readPressure() / 100.0f;
  d.temperature_c  = htu.readTemperature();
  d.humidity_pct   = htu.readHumidity();
  // battery_v is set in setup() to avoid redundant ADC reads
  d.sensor_ok      = true;

  Serial.printf("P=%.2f hPa T=%.2f C H=%.1f%% Bat=%.2fV\n",
    d.pressure_hpa, d.temperature_c, d.humidity_pct, d.battery_v);

  return d;
}

// Trend Analysis

void updateHistory(float pressure, float humidity, float temperature) {
  rtc_pressure[rtc_head]    = pressure;
  rtc_humidity[rtc_head]    = humidity;
  rtc_temperature[rtc_head] = temperature;
  rtc_head = (rtc_head + 1) % HISTORY_LEN;
  if (rtc_count < HISTORY_LEN) rtc_count++;
}

float calcTrend(float* buf, uint8_t count) {
  if (count < 2) return 0.0f;
  float sum_x = 0, sum_y = 0, sum_xy = 0, sum_x2 = 0;
  for (uint8_t i = 0; i < count; i++) {
    uint8_t idx = (rtc_head - count + i + HISTORY_LEN) % HISTORY_LEN;
    sum_x  += i;
    sum_y  += buf[idx];
    sum_xy += i * buf[idx];
    sum_x2 += i * i;
  }
  float denom = (count * sum_x2 - sum_x * sum_x);
  if (fabsf(denom) < 1e-6f) return 0.0f;
  return (count * sum_xy - sum_x * sum_y) / denom;
}

// Open-Meteo Fetch

ForecastData fetchForecast() {
  ForecastData f = {};

  String url = String("https://api.open-meteo.com/v1/forecast?latitude=") +
               LATITUDE + "&longitude=" + LONGITUDE +
               "&hourly=precipitation_probability,temperature_2m,relative_humidity_2m"
               "&forecast_hours=3&timezone=Asia%2FKolkata";

  WiFiClientSecure client;
  client.setInsecure();          
  HTTPClient http;
  http.begin(client, url);
  http.setTimeout(10000);
  int code = http.GET();

  if (code != 200) {
    Serial.printf("http fail: %d\n", code);
    http.end();
    f.fetch_ok = false;
    return f;
  }

  WiFiClient* stream = http.getStreamPtr();
  JsonDocument doc;
  DeserializationError err = deserializeJson(doc, *stream);
  http.end();

  if (err) {
    Serial.printf("json error: %s\n", err.c_str());
    f.fetch_ok = false;
    return f;
  }

  JsonArray rain_arr  = doc["hourly"]["precipitation_probability"];
  JsonArray temp_arr  = doc["hourly"]["temperature_2m"];
  JsonArray hum_arr   = doc["hourly"]["relative_humidity_2m"];

  float rain_sum = 0, temp_sum = 0, hum_sum = 0;
  int   n = min((int)rain_arr.size(), 3);
  if (n == 0) {
    Serial.println("empty forecast arrays");
    f.fetch_ok = false;
    return f;
  }
  for (int i = 0; i < n; i++) {
    rain_sum += rain_arr[i].as<float>();
    temp_sum += temp_arr[i].as<float>();
    hum_sum  += hum_arr[i].as<float>();
  }

  f.rain_chance      = rain_sum / n;
  f.forecast_temp_c  = temp_sum / n;
  f.forecast_humidity= hum_sum  / n;
  f.fetch_ok         = true;

  Serial.printf("forecast: rain=%.1f%% temp=%.1fC hum=%.1f%%\n",
    f.rain_chance, f.forecast_temp_c, f.forecast_humidity);

  return f;
}

// Bayesian-style Local Adjustment

static float toLogit(float p_pct) {
  float p = constrain(p_pct / 100.0f, 0.001f, 0.999f);
  return logf(p / (1.0f - p));
}

static float fromLogit(float logit) {
  return 100.0f / (1.0f + expf(-logit));
}

LocalForecast adjustForecast(const ForecastData& fc, uint8_t history_count) {
  LocalForecast lf = {};

  if (!fc.fetch_ok) {
    lf.adjusted_rain_chance = 50.0f;
    lf.condition_label      = "No Forecast";
    return lf;
  }

  float logit = toLogit(fc.rain_chance);

  if (history_count >= 2) {
    float dp = calcTrend(rtc_pressure,    history_count);
    float dh = calcTrend(rtc_humidity,    history_count);
    float dt = calcTrend(rtc_temperature, history_count);

// Pressure Trend
    if      (dp < -0.8f) logit += 1.5f;
    else if (dp < -0.3f) logit += 0.6f;
    else if (dp >  0.8f) logit -= 1.2f;
    else if (dp >  0.3f) logit -= 0.4f;

// Humidity Trend
    if      (dh >  5.0f) logit += 0.8f;
    else if (dh >  2.0f) logit += 0.3f;
    else if (dh < -5.0f) logit -= 0.6f;
    else if (dh < -2.0f) logit -= 0.2f;

    float cur_hum = rtc_humidity[(rtc_head - 1 + HISTORY_LEN) % HISTORY_LEN];
    if (dt < -0.5f && cur_hum > 75.0f) logit += 0.4f;
  }

  lf.adjusted_rain_chance = fromLogit(logit);

// Condition label
  float r = lf.adjusted_rain_chance;
  if      (r < 15.0f) lf.condition_label = "Clear";
  else if (r < 35.0f) lf.condition_label = "Partly Cloudy";
  else if (r < 55.0f) lf.condition_label = "Chance of Rain";
  else if (r < 75.0f) lf.condition_label = "Likely Rain";
  else                lf.condition_label = "Rain Expected";

  return lf;
}

// WiFi

bool connectWiFi() {
  WiFi.mode(WIFI_STA);
  WiFi.begin(WIFI_SSID, WIFI_PASSWORD);
  Serial.print("wifi connecting");
  for (int i = 0; i < 20; i++) {
    if (WiFi.status() == WL_CONNECTED) {
      Serial.printf(" ok\n");
      return true;
    }
    delay(500);
    Serial.print(".");
  }
  Serial.println(" fail");
  WiFi.disconnect(true);
  WiFi.mode(WIFI_OFF);
  return false;
}

// Output

void printResult(const SensorData& s, const ForecastData& fc, const LocalForecast& lf) {
  Serial.println("--- meteonode ---");
  Serial.printf("boot #%u\n", rtc_boot_count);
  Serial.printf("battery: %.2fV\n", s.battery_v);
  if (s.sensor_ok) {
    Serial.printf("pressure: %.2f hPa\n", s.pressure_hpa);
    Serial.printf("temp: %.1fC\n", s.temperature_c);
    Serial.printf("humidity: %.1f%%\n", s.humidity_pct);
  }
  if (fc.fetch_ok) {
    Serial.printf("open-meteo rain: %.1f%%\n", fc.rain_chance);
  }
  Serial.printf("local adjusted: %.1f%%\n", lf.adjusted_rain_chance);
  Serial.printf("condition: %s\n", lf.condition_label.c_str());
  Serial.println("----------------");
}

// Setup

void setup() {
  Serial.begin(115200);
  delay(200);

  pinMode(LATCH_HOLD_PIN, OUTPUT);
  digitalWrite(LATCH_HOLD_PIN, HIGH);

  rtc_boot_count++;
  Serial.printf("\nboot %u\n", rtc_boot_count);

  float bat = readBatteryVoltage();
  Serial.printf("bat: %.2fV\n", bat);

  if (bat < BAT_CRITICAL_V) {
    cutPower();
  }

  bool skip_wifi = (bat < BAT_LOW_V);
  if (skip_wifi) {
    Serial.println("low battery, skipping wifi");
  }

  Wire.begin();
  SensorData sensors = readSensors();
  sensors.battery_v = bat;

  if (sensors.sensor_ok) {
    updateHistory(sensors.pressure_hpa, sensors.humidity_pct, sensors.temperature_c);
  }

  ForecastData forecast = {};
  if (!skip_wifi) {
    if (connectWiFi()) {
      forecast = fetchForecast();
      WiFi.disconnect(true);
      WiFi.mode(WIFI_OFF);
    }
  }

  LocalForecast local = adjustForecast(forecast, rtc_count);
  printResult(sensors, forecast, local);

  Serial.printf("sleeping %ds\n", SLEEP_SECONDS);
  Serial.flush();
  esp_sleep_enable_timer_wakeup((uint64_t)SLEEP_SECONDS * 1000000ULL);
  esp_deep_sleep_start();
}

void loop() {
}

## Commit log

2026-05-13 add the kicad_sch file
    [metonode.kicad_sch]
2026-05-13 Making a hardware folder and adding the MeteoNode.kicad_sch file to it
    [MeteoNode.kicad_sch]
2026-05-13 Adding the Schematic_Export
2026-05-13 Adding the MeteoNode.kicad_pro file
2026-05-14 Added the BOM
    [MeteoNode-bom.csv]
2026-05-14 Moved the BOM to the root
    [MeteoNode-bom.csv]
2026-05-18 Added a new journal entry
    Documented CAD development progress for battery compartment and pole assembly, including design decisions and challenges faced during the process.
2026-05-18 Added the Main Electronics box.step file
    [Main Electronics Box.step]
2026-05-18 Made a Cad files folder and moved the "Main Electronics Box.step" to it
    [Main Electronics Box.step]
2026-05-18 Added the Battery Box's CAD file
    [Battery Box.step]
2026-05-18 Added the Pole-Mount Braket's CAD file
    [Pole-Mount Bracket.step]
2026-05-18 Added the Pole's CAD file
    [Pole.step]
2026-05-18 Added CAD assembly
    [Assembly.step]
2026-05-19 Fix spelling errors in MeteoNode-bom.csv
    [MeteoNode-bom.csv]
2026-05-19 remove dead sleep code in cutPower(), halt if latch fails
    [Firmware.ino]
2026-06-10 add Updated schematic
    [MeteoNode.kicad_sch]
2026-06-10 add update schematic pdf
2026-06-10 Add Wiring Diagram
2026-06-10 Rename Wiring Diagram.png to wiring_diagram.png
2026-06-10 Update README with OnShape link and wiring diagram
    Added OnShape link and wiring diagram to README.
2026-06-10 Update instructions for viewing wiring diagram
2026-06-10 Modify ESP32-DevKitC price and vendor
    [bom.csv]
2026-06-12 add cad screenshots
2026-06-12 Add CAD screenshots to README
